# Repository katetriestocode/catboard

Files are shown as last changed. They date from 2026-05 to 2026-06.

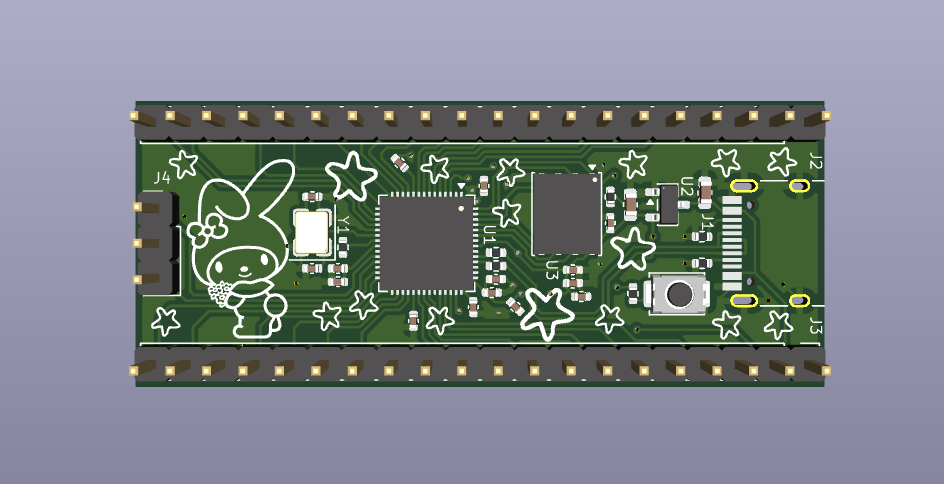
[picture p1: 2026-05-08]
media/Screenshot 2026-05-08 at 14.56.30.png

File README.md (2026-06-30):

# catboard

devboard following hackclub guide with 128Mb (new!) memory with rp2040 with a long cat on it, as well as mymelody and stars! 
I made this with beefy graphics projects in mind, to be able to whitstand larger graphics :) I also really wanted to have a custom devboard that suits my needs and can work for all my project prototypes!
This is it built and soldered up:





This is the back:



This is the front (but will be white!):



This is the schematic:



And this is the pcb:



|Designator|Footprint|Quantity|Value|LCSC Part #|
|---|---|---|---|---|
|"C1-C10"|0402|2|1uf|CL05A105KA5NQNC|
|"C11-C9"|0402|11|0.1uf|CL05B104KO5NNNC|
|"C13-C14"|0603|2|10uf|CL10A106KP8NNNC|
|"C15-C16"|0402|2|33pF|0402CG330J500NT|
|J1|USB_C_Receptacle_HRO_TYPE-C-31-M-12|1|USB_C_Receptacle_USB2.0_14P|TYPE-C-31-M-12|
|"R1-R2"|0402|2|5.1k|0402WGF5101TCE|
|"R3-R4"|0402|2|27|0402WGF270JTCE|
|"R5-R7"|0402|2|1K|0402WGF1001TCE|
|R6|0402|1|10k|0402WGF1002TCE|
|SW1|SW_Push_SPST_NO_Alps_SKRK|1|SW_Push|TS-1088-AR02016|
|U1|QFN-56-1EP_7x7mm_P0.4mm_EP3.2x3.2mm|1|n/a|RP2040|
|U2|SOT-23|1|MCP1700x-330xxTT|MCP1700T-3302E/TT|
|U3|WSON-8-1EP_6x5mm_P1.27mm_EP3.4x4.3mm|1|n/a|W25Q128JVP|
|Y1|Crystal_SMD_3225-4Pin_3.2x2.5mm|1|12 MHz|X322512MSB4SI|

|Item|Cost|
|---|---|
|PCBA|50.70$|
|shipping|1.50$|

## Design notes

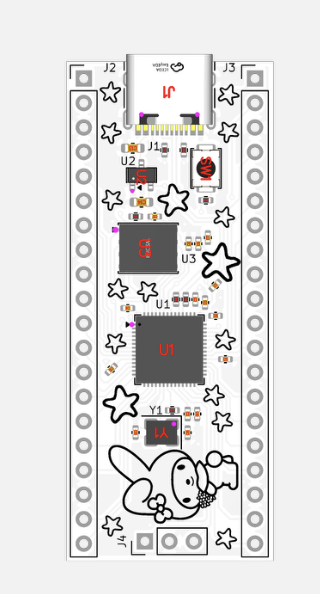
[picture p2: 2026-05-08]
media/Screenshot 2026-05-08 at 14.57.11.png

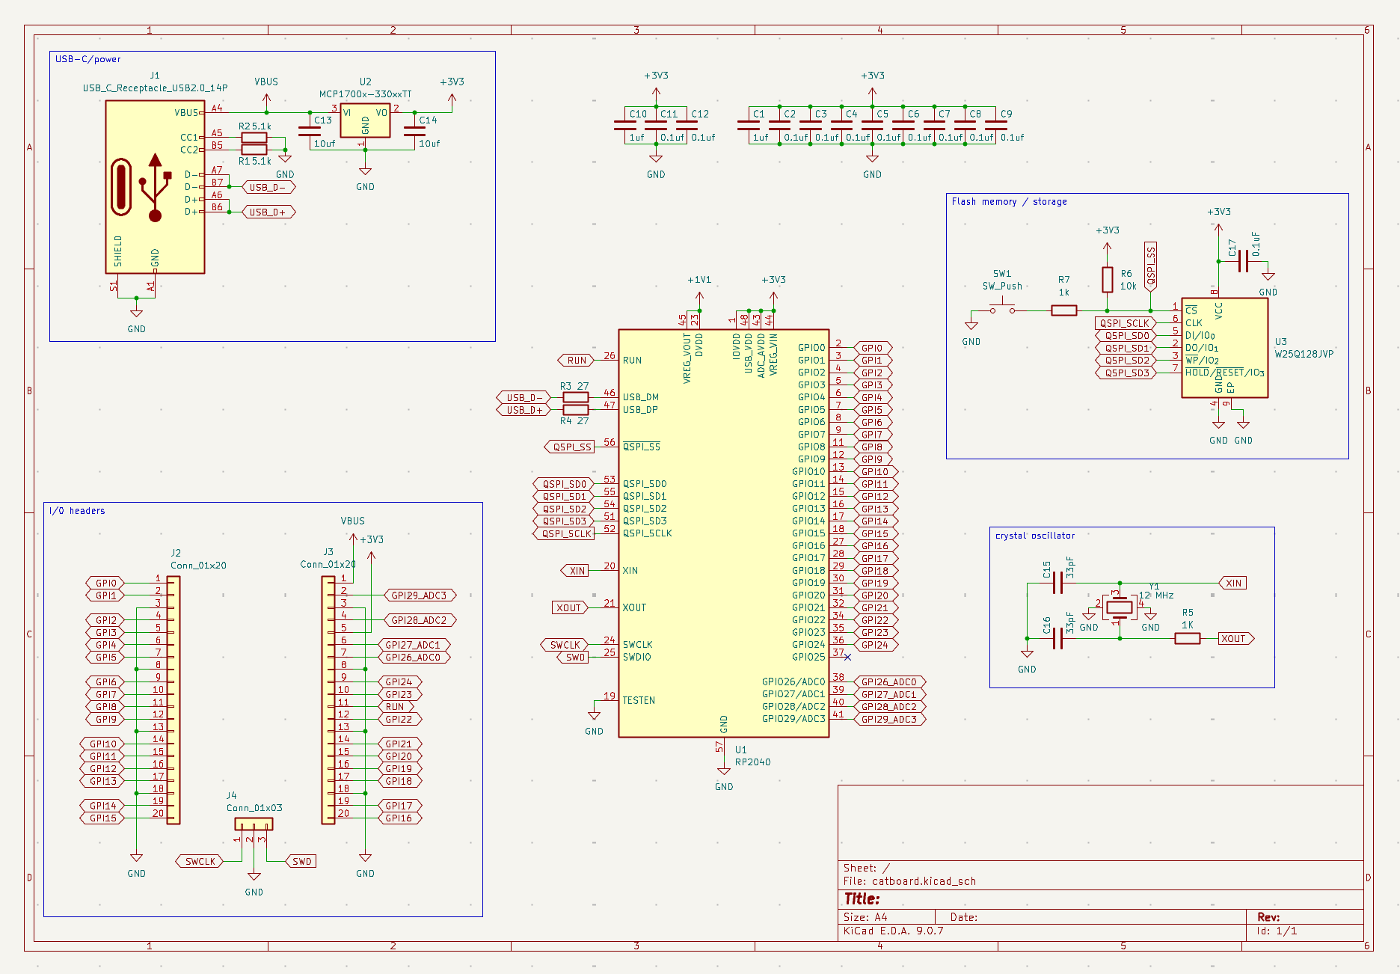
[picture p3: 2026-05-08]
media/Screenshot 2026-05-08 at 14.56.07.png

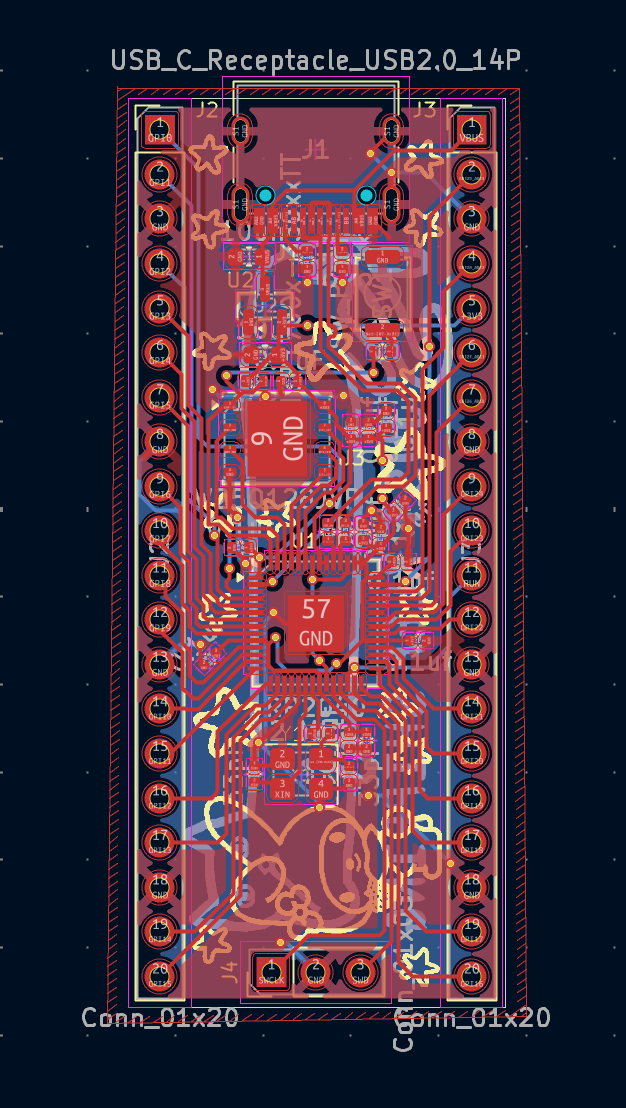
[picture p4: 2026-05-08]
media/Screenshot 2026-05-08 at 14.55.54.png

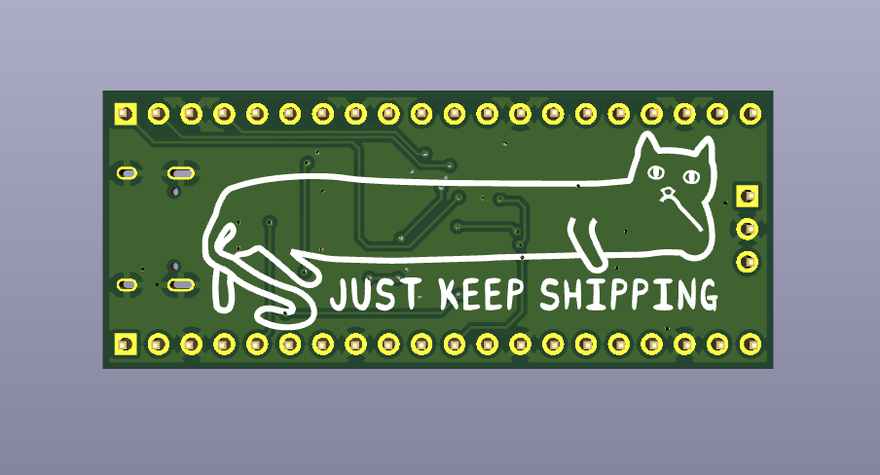
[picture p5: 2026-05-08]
media/Screenshot 2026-05-08 at 14.56.50.png

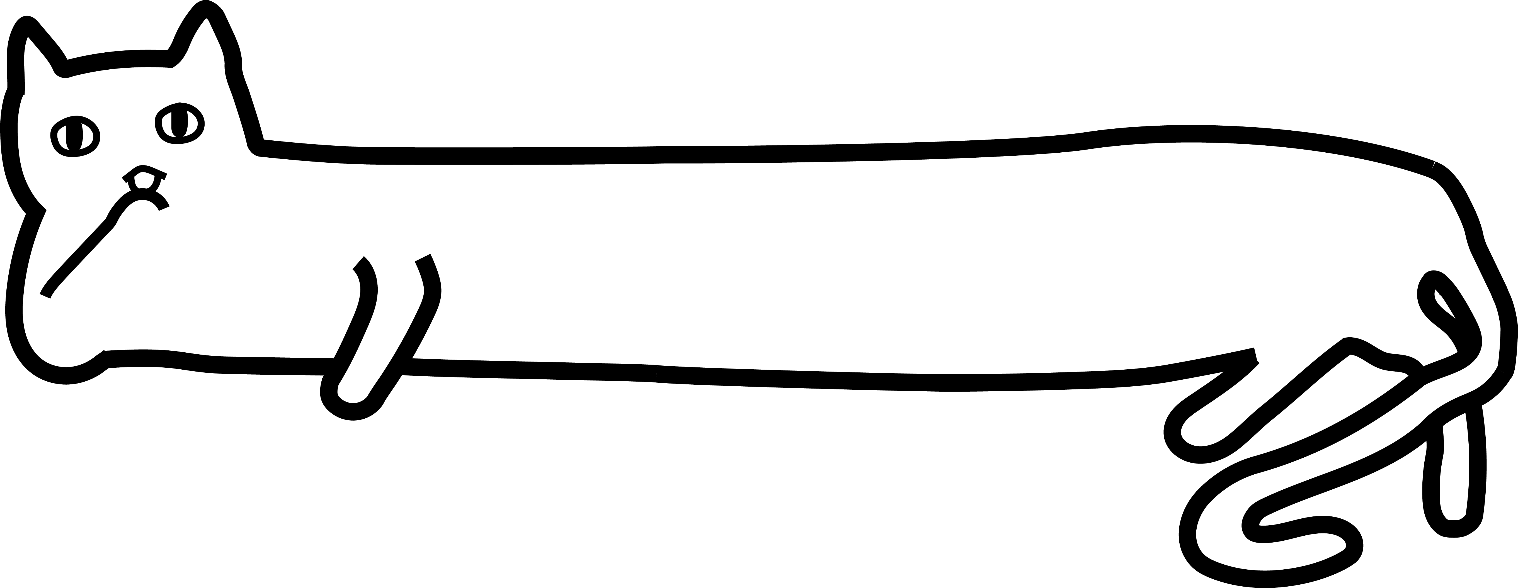
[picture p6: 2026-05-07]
illustrator/Untitled-10.png

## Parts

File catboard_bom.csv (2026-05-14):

Designator | Footprint | Quantity | Value | LCSC Part #
C1-C10 | 402 | 2 | 1uf | CL05A105KA5NQNC
C11-C12-C17-C2-C3-C4-C5-C6-C7-C8-C9 | 402 | 11 | 0.1uf | CL05B104K05NNNC
C13-C14 | 603 | 2 | 10uf | CL10A106KP8NNNC
C15-C16 | 402 | 2 | 33pF | 0402CG330J500NT
J1 | USB_C_Receptacle_HRO_TYPE-C-31-M-12 | 1 | USB_C_Receptacle_USB2.0_14P | TYPE-C-31-M-12
R1-R2 | 402 | 2 | 5.1k | 0402WGF5101TCE
R3-R4 | 402 | 2 | 27 | 0402WGF270JTCE
R5-R7 | 402 | 2 | 1K | 0402WGF1001TCE
R6 | 402 | 1 | 10k | 0402WGF1002TCE
SW1 | SW_Push_SPST_NO_Alps_SKRK | 1 | SW_Push | TS-1088-AR02016
U1 | QFN-56-1EP_7x7mm_P0.4mm_EP3.2x3.2mm | 1 | RP2040 | RP2040
U2 | SOT-23 | 1 | MCP1700x-330xxTT | MCP1700T-3302E/TT
U3 | WSON-8-1EP_6x5mm_P1.27mm_EP3.4x4.3mm | 1 | W25Q128JVP | W25Q128JVP
Y1 | Crystal_SMD_3225-4Pin_3.2x2.5mm | 1 | 12 MHz | X322512MSB4SI
total price PCBA: 50.70$
shipping: 1.5$

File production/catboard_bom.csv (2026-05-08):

Designator | Footprint | Quantity | Value | LCSC Part #
C1, C10 | 0402 | 2 | 1uf
C11, C12, C17, C2, C3, C4, C5, C6, C7, C8, C9 | 0402 | 11 | 0.1uf
C13, C14 | 0603 | 2 | 10uf
C15, C16 | 0402 | 2 | 33pF
J1 | USB_C_Receptacle_HRO_TYPE-C-31-M-12 | 1 | USB_C_Receptacle_USB2.0_14P
J2, J3 | PinHeader_1x20_P2.54mm_Vertical | 2 | Conn_01x20
J4 | PinHeader_1x03_P2.54mm_Vertical | 1 | Conn_01x03
R1, R2 | 0402 | 2 | 5.1k
R3, R4 | 0402 | 2 | 27
R5, R7 | 0402 | 2 | 1K
R6 | 0402 | 1 | 10k
SW1 | SW_Push_SPST_NO_Alps_SKRK | 1 | SW_Push
U1 | QFN-56-1EP_7x7mm_P0.4mm_EP3.2x3.2mm | 1 | RP2040
U2 | SOT-23 | 1 | MCP1700x-330xxTT
U3 | WSON-8-1EP_6x5mm_P1.27mm_EP3.4x4.3mm | 1 | W25Q128JVP
Y1 | Crystal_SMD_3225-4Pin_3.2x2.5mm | 1 | 12 MHz

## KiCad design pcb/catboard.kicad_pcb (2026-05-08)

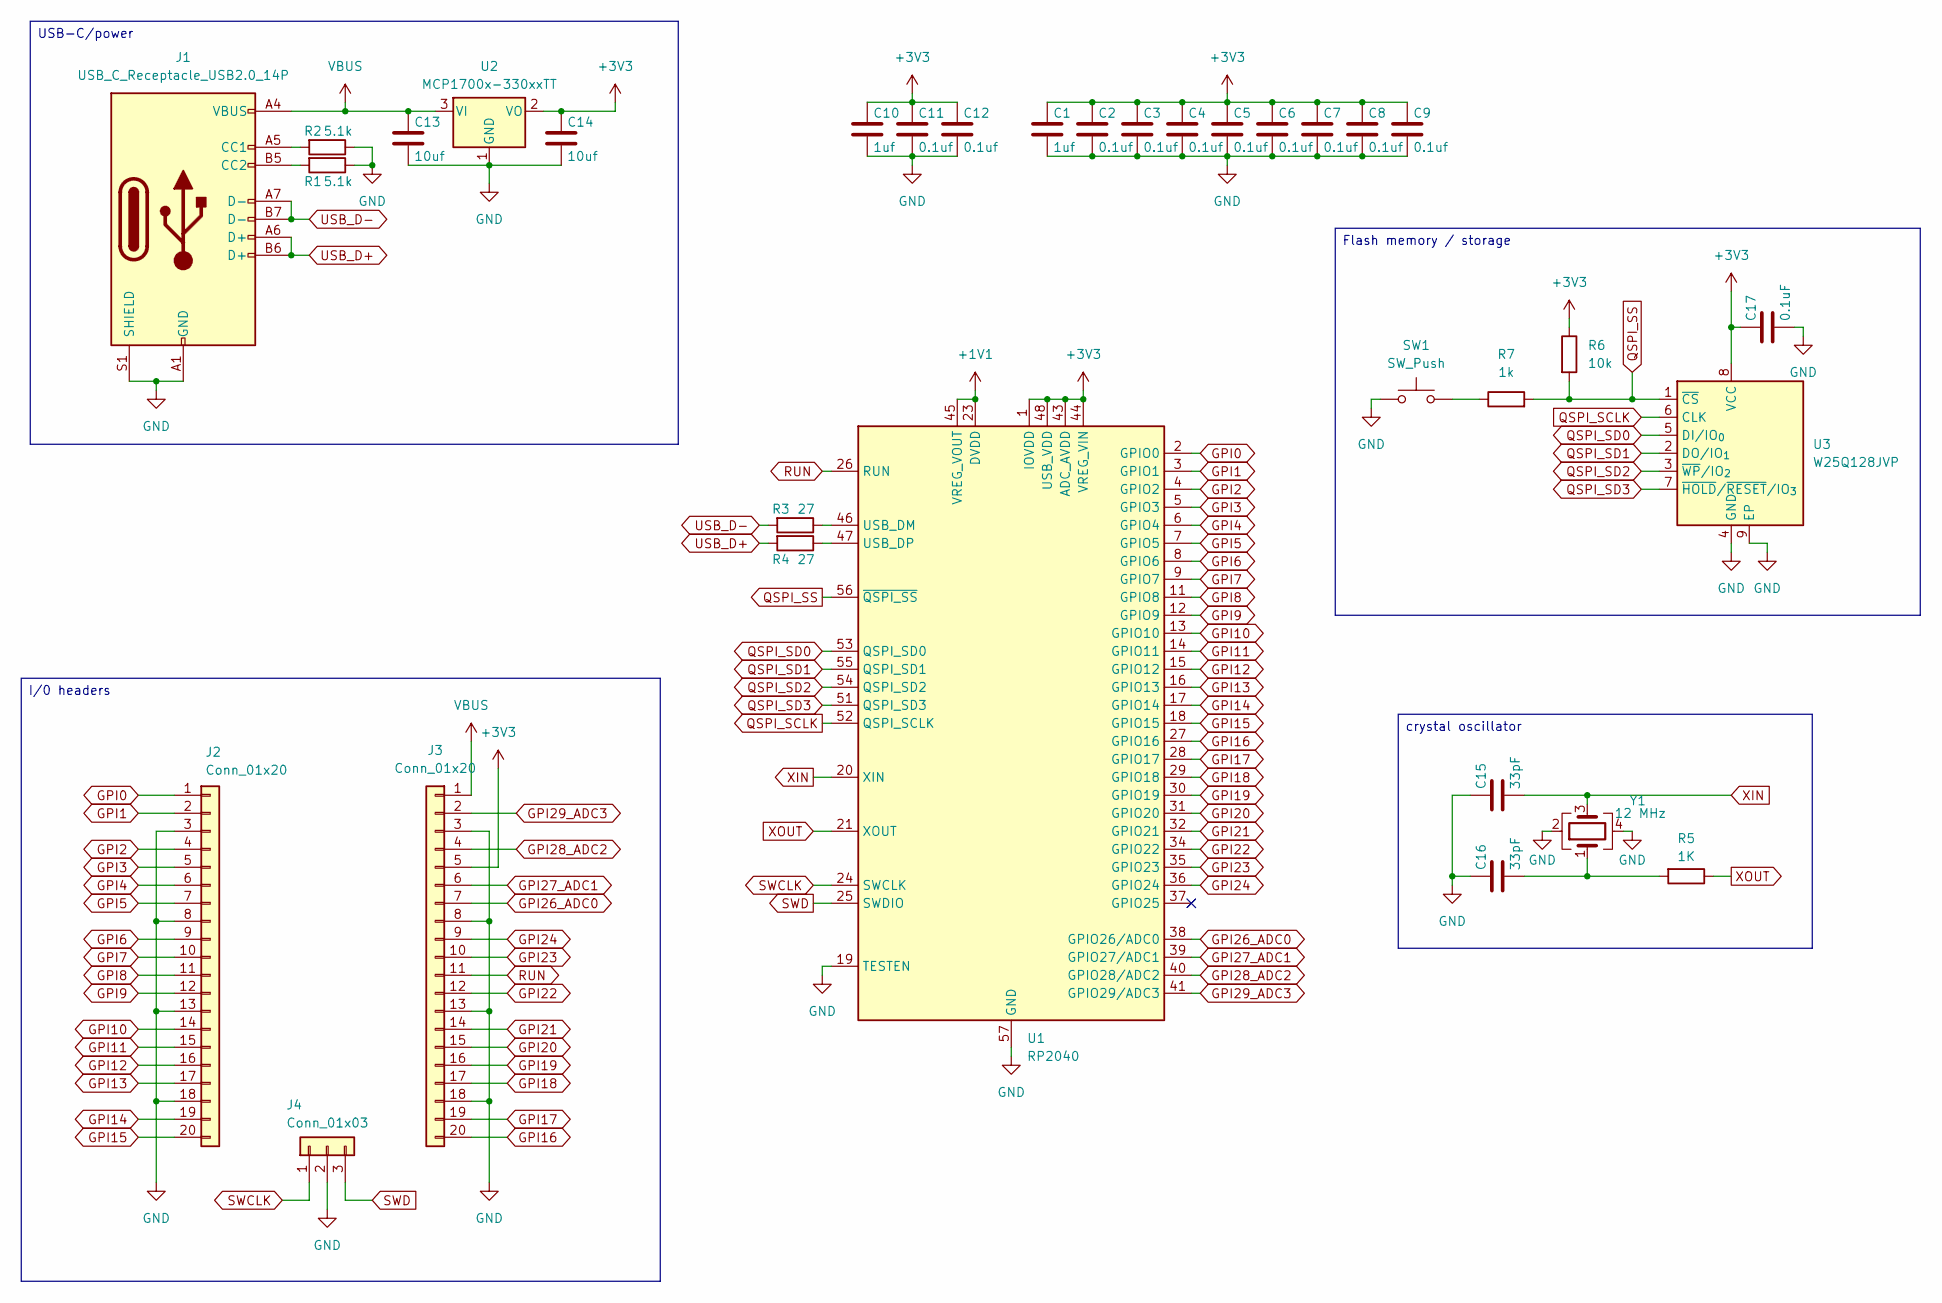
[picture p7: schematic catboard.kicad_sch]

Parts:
C1, C10: 1uf; C_0402_1005Metric
C2, C3, C4, C5, C6, C7, C8, C9, C11, C12: 0.1uf; C_0402_1005Metric
C13, C14: 10uf; C_0603_1608Metric
C15, C16: 33pF; C_0402_1005Metric
C17: 0.1uF; C_0402_1005Metric
J1: USB_C_Receptacle_USB2.0_14P; USB_C_Receptacle_HRO_TYPE-C-31-M-12
J2, J3: Conn_01x20; PinHeader_1x20_P2.54mm_Vertical
J4: Conn_01x03; PinHeader_1x03_P2.54mm_Vertical
R1, R2: 5.1k; R_0402_1005Metric
R3, R4: 27; R_0402_1005Metric
R5: 1K; R_0402_1005Metric
R6: 10k; R_0402_1005Metric
R7: 1k; R_0402_1005Metric
SW1: SW_Push; SW_Push_SPST_NO_Alps_SKRK
U1: RP2040; QFN-56-1EP_7x7mm_P0.4mm_EP3.2x3.2mm
U2: MCP1700x-330xxTT; SOT-23
U3: W25Q128JVP; WSON-8-1EP_6x5mm_P1.27mm_EP3.4x4.3mm
Y1: 12 MHz; Crystal_SMD_3225-4Pin_3.2x2.5mm

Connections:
+1V1: U1.23 (DVDD), U1.45 (VREG_VOUT), U1.50 (DVDD)
+3V3: C1.1, C2.1, C3.1, C4.1, C5.1, C6.1, C7.1, C8.1, C9.1, C10.1, C11.1, C12.1, C14.1, C17.1, J3.5, R6.1, U1.1 (IOVDD), U1.10 (IOVDD), U1.22 (IOVDD), U1.33 (IOVDD), U1.42 (IOVDD), U1.43 (ADC_AVDD), U1.44 (VREG_VIN), U1.48 (USB_VDD), U1.49 (IOVDD), U2.2 (VO), U3.8 (VCC)
GND: C1.2, C2.2, C3.2, C4.2, C5.2, C6.2, C7.2, C8.2, C9.2, C10.2, C11.2, C12.2, C13.2, C14.2, C15.1, C16.1, C17.2, J1.A1 (GND), J1.A12 (GND), J1.B1 (GND), J1.B12 (GND), J1.S1 (SHIELD), J2.3, J2.8, J2.13, J2.18, J3.3, J3.8, J3.13, J3.18, J4.2, R1.1, R2.1, SW1.1, U1.19 (TESTEN), U1.57 (GND), U2.1 (GND), U3.4 (GND), U3.9 (EP), Y1.2 (G), Y1.4 (G)
GPI0: J2.1, U1.2 (GPIO0)
GPI1: J2.2, U1.3 (GPIO1)
GPI2: J2.4, U1.4 (GPIO2)
GPI3: J2.5, U1.5 (GPIO3)
GPI4: J2.6, U1.6 (GPIO4)
GPI5: J2.7, U1.7 (GPIO5)
GPI6: J2.9, U1.8 (GPIO6)
GPI7: J2.10, U1.9 (GPIO7)
GPI8: J2.11, U1.11 (GPIO8)
GPI9: J2.12, U1.12 (GPIO9)
GPI10: J2.14, U1.13 (GPIO10)
GPI11: J2.15, U1.14 (GPIO11)
GPI12: J2.16, U1.15 (GPIO12)
GPI13: J2.17, U1.16 (GPIO13)
GPI14: J2.19, U1.17 (GPIO14)
GPI15: J2.20, U1.18 (GPIO15)
GPI16: J3.20, U1.27 (GPIO16)
GPI17: J3.19, U1.28 (GPIO17)
GPI18: J3.17, U1.29 (GPIO18)
GPI19: J3.16, U1.30 (GPIO19)
GPI20: J3.15, U1.31 (GPIO20)
GPI21: J3.14, U1.32 (GPIO21)
GPI22: J3.12, U1.34 (GPIO22)
GPI23: J3.10, U1.35 (GPIO23)
GPI24: J3.9, U1.36 (GPIO24)
GPI26_ADC0: J3.7, U1.38 (GPIO26/ADC0)
GPI27_ADC1: J3.6, U1.39 (GPIO27/ADC1)
GPI28_ADC2: J3.4, U1.40 (GPIO28/ADC2)
GPI29_ADC3: J3.2, U1.41 (GPIO29/ADC3)
unnamed: C16.2, R5.2, Y1.1
unnamed: J1.A5 (CC1), R2.2
unnamed: J1.B5 (CC2), R1.2
unnamed: R7.1, SW1.2
unnamed: R3.1, U1.46 (USB_DM)
unnamed: R4.1, U1.47 (USB_DP)
QSPI_SCLK: U1.52 (QSPI_SCLK), U3.6 (CLK)
QSPI_SD0: U1.53 (QSPI_SD0), U3.5 (DI/IO_{0})
QSPI_SD1: U1.55 (QSPI_SD1), U3.2 (DO/IO_{1})
QSPI_SD2: U1.54 (QSPI_SD2), U3.3 (~WP/IO_{2})
QSPI_SD3: U1.51 (QSPI_SD3), U3.7 (~HOLD/~RESET/IO_{3})
QSPI_SS: R6.2, R7.2, U1.56 (~QSPI_SS), U3.1 (~CS)
RUN: J3.11, U1.26 (RUN)
SWCLK: J4.1, U1.24 (SWCLK)
SWD: J4.3, U1.25 (SWDIO)
USB_D+: J1.A6 (D+), J1.B6 (D+), R4.2
USB_D-: J1.A7 (D-), J1.B7 (D-), R3.2
VBUS: C13.1, J1.A4 (VBUS), J1.A9 (VBUS), J1.B4 (VBUS), J1.B9 (VBUS), J3.1, U2.3 (VI)
XIN: C15.2, U1.20 (XIN), Y1.3
XOUT: R5.1, U1.21 (XOUT)

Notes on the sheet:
I/0 headers
USB-C/power
Flash memory / storage
crystal oscillator

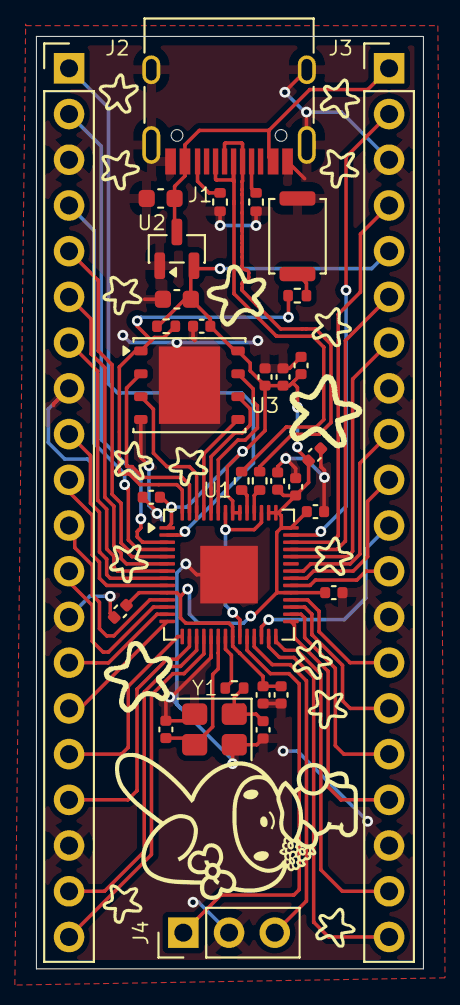
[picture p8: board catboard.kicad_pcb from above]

Board: 2 copper layers, 21.5 x 51.8 mm, 33 parts (0 on the bottom side), 52 nets.

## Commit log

2026-05-07 Update README with BOM file location
    Added note about BOM file location in README.
2026-05-08 get ready for trouble make it double
    [catboard_bom.csv]
2026-05-14 Add BOM table to README
    Added a Bill of Materials (BOM) table to the README.
2026-05-14 bom update
    [bomcatboard.xlsx, bomcatboardwithshippingandcodes.csv]
2026-05-14 fix again
    [catboard_bomexcelfile.xls]
